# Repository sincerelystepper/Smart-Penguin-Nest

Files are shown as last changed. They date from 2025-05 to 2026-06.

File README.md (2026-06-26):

# Smart Penguin Nest

<p align="center">

# Embedded Environmental Monitoring Platform for African Penguin Conservation

*An ESP32-based multi-sensor embedded instrumentation platform developed for non-invasive wildlife monitoring, environmental data acquisition, and precision weight measurement.*

<br>







</p>

---

> **Engineering Portfolio Project**
>
> This repository documents the design and development of the embedded electronics subsystem for the **Smart Penguin Nest**, a multidisciplinary engineering project created to support environmental monitoring and conservation research of African Penguins through autonomous sensing, embedded instrumentation, and wireless data acquisition.

---

# Table of Contents

* [Project Overview](#project-overview)
* [Research Background](#research-background)
* [Engineering Objectives](#engineering-objectives)
* [System Architecture](#system-architecture)
* [Embedded Electronics Development](#embedded-electronics-development)
* [Hardware Platform](#hardware-platform)
* [Sensor Integration](#sensor-integration)
* [Firmware Architecture](#firmware-architecture)
* [Electronics Design](#electronics-design)
* [Load Cell Calibration](#load-cell-calibration)
* [Communication Architecture](#communication-architecture)
* [Validation & Testing](#validation--testing)
* [Engineering Challenges](#engineering-challenges)
* [Project Gallery](#project-gallery)
* [My Contributions](#my-contributions)
* [Future Improvements](#future-improvements)

---

# Project Overview

The **Smart Penguin Nest** is a prototype embedded environmental monitoring platform developed to assist wildlife researchers in continuously monitoring the environmental conditions experienced by African Penguins during breeding and molting.

The project combines precision instrumentation, environmental sensing, embedded firmware, and wireless communication into a single autonomous monitoring platform capable of acquiring, processing, and transmitting data from multiple sensors.

Although initially developed as a laboratory prototype, the hardware architecture and firmware were designed with future field deployment in mind. Following successful subsystem validation using modular development hardware, a complete electronic schematic was produced in **KiCad** to support future custom PCB revisions and deployment-ready hardware.

This repository focuses specifically on the **embedded electronics engineering**, including firmware development, sensor integration, hardware validation, calibration, and electronic design.

---

# Research Background

African Penguins (*Spheniscus demersus*) have experienced a significant decline in population over recent decades, making continuous ecological monitoring increasingly important for conservation research.

Understanding how environmental conditions influence breeding success, nesting behaviour, and molting requires reliable long-term data acquisition systems capable of operating with minimal disturbance to the animals.

The Smart Penguin Nest project was conceived as a multidisciplinary solution that combines mechanical design, software, and embedded electronics to automate the collection of environmental and physiological measurements from penguin nesting environments.

The embedded subsystem developed within this project provides the sensing and instrumentation layer responsible for acquiring reliable field measurements that can later be analysed by researchers.

---

# Engineering Objectives

The embedded monitoring platform was designed around the following engineering objectives:

* Design a modular embedded instrumentation platform.
* Integrate multiple environmental and physiological sensors.
* Perform accurate body weight measurement using precision load-cell instrumentation.
* Acquire temperature and humidity measurements within the nesting enclosure.
* Enable RFID-based identification capabilities.
* Support infrared temperature sensing.
* Implement wireless communication for remote data transmission.
* Produce a scalable electronics architecture suitable for future PCB implementation.
* Validate subsystem performance through laboratory testing and calibration.

---

# Why This Project Matters

While the immediate application targets wildlife conservation, the engineering principles demonstrated throughout this project are directly applicable to numerous embedded systems domains, including:

| Application | Relevance |
| --- | --- |
| Industrial IoT | Multi-sensor data acquisition  |
| Precision Agriculture | Environmental monitoring |
| Livestock Monitoring | Animal health instrumentation  |
| Smart Buildings | Environmental sensing |
| Cold Chain Monitoring | Temperature logging |
| Industrial Automation | Embedded sensor integration |
| Remote Telemetry | Wireless monitoring systems |
| Scientific Instrumentation | Precision embedded measurement |

The project demonstrates the complete engineering workflow required to transform individual electronic components into an integrated embedded sensing platform suitable for real-world deployment.

---

# Embedded Electronics Development

The embedded subsystem was developed using an iterative engineering workflow, beginning with individual sensor evaluation before progressing toward complete system integration.

Rather than immediately designing a custom PCB, the hardware was first assembled using modular development boards and prototyping components. This accelerated firmware development, simplified subsystem debugging, and allowed each sensing technology to be independently characterized before full system integration.

Following successful laboratory validation, the complete electronic design was captured in **KiCad**, providing a foundation for future PCB revisions and deployment-ready hardware.

The development process followed the typical lifecycle of an embedded instrumentation project:

```text
Requirements Definition
        │
        ▼
Component Selection
        │
        ▼
Power Subsystem Validation
        │
        ▼
Sensor Bring-up
        │
        ▼
Individual Driver Development
        │
        ▼
Sensor Calibration
        │
        ▼
Integrated Firmware Development
        │
        ▼
Wireless Communication
        │
        ▼
Hardware Validation
        │
        ▼
Electronic Schematic Capture
        │
        ▼
Future PCB Design
```

This incremental development approach significantly reduced integration risk by validating each subsystem independently before combining them into the complete monitoring platform.

---

# Hardware Bring-Up

Initial development focused on constructing a working prototype capable of validating each hardware subsystem independently.

The prototype platform combined:

* ESP32 development board
* Precision load-cell interface
* Environmental sensing modules
* RFID identification hardware
* Infrared temperature sensing
* Regulated power distribution
* Wireless communication

Each subsystem was individually verified before being integrated into the complete embedded platform.

<p align="center">

</p>

<p align="center">
<i>Figure 1 — Prototype embedded monitoring platform assembled during subsystem integration and laboratory validation.</i>
</p>

---

# Power Subsystem Validation

Power integrity is one of the most critical aspects of any embedded system.

Before integrating sensors, the power architecture was characterized using laboratory instrumentation to verify voltage regulation, current consumption, and regulator stability under varying operating conditions.

Validation activities included:

* DC-DC buck converter adjustment
* Output voltage verification
* Current consumption measurements
* Regulator stability testing
* System power-up validation

<p align="center">

</p>

<p align="center">
<i>Figure 2 — Initial subsystem power-up using a laboratory bench power supply prior to sensor integration.</i>
</p>

<p align="center">

</p>

<p align="center">
<i>Figure 3 — Output voltage calibration and verification of the DC-DC buck converter before powering embedded electronics.</i>
</p>

<p align="center">

</p>

<p align="center">
<i>Figure 4 — Current consumption measurements performed during hardware characterization and subsystem validation.</i>
</p>

These validation steps ensured reliable power delivery to the ESP32 and all connected sensors before progressing to firmware integration and long-duration testing.

---

---

# Sensor Integration

A primary objective of the Smart Penguin Nest platform was the reliable acquisition of environmental and physiological measurements from multiple sensing technologies.

Rather than relying on a single sensor, the embedded platform integrates a heterogeneous collection of digital, analog and precision instrumentation devices, each selected to monitor a different aspect of the nesting environment.

Each sensor required dedicated firmware development, hardware integration, interface validation and system-level testing before being incorporated into the complete embedded monitoring platform.

---

# Embedded Sensor Suite

| Sensor | Purpose | Interface  |
| --- | --- | --- |
| **HX711 + Load Cell** | Precision body weight measurement | 24-bit ADC |
| **DS18B20** | Ambient temperature sensing | 1-Wire |
| **SHTC3** | Temperature & Relative Humidity | I²C |
| **MLX90614** | Non-contact infrared temperature measurement | I²C |
| **MFRC522** | RFID identification | SPI |

The modular firmware architecture allows each sensing subsystem to operate independently while contributing measurements to a common acquisition and communication framework.

---

# Precision Weight Measurement

## HX711 Load Cell Instrumentation

One of the primary engineering challenges was the accurate measurement of penguin body mass without disturbing the animal.

This was achieved using a strain-gauge load cell coupled with the **HX711**, a precision 24-bit analog-to-digital converter specifically designed for load-cell instrumentation.

Unlike conventional ADCs integrated into microcontrollers, the HX711 provides extremely high measurement resolution together with a programmable gain amplifier, making it particularly suitable for low-level bridge sensor measurements.

The embedded firmware performs:

* Load-cell initialization
* Zero-offset (tare) measurement
* Continuous sampling
* Digital averaging
* Calibration factor application
* Stable weight computation

Calibration parameters are stored within the ESP32's non-volatile memory, allowing the system to preserve calibration between power cycles without requiring repeated field calibration.

<p align="center">

</p>

<p align="center">
<i>Figure 5 — Load-cell calibration procedure used to determine scale factors and improve measurement accuracy.</i>
</p>

---

# Environmental Monitoring

## Temperature Measurement

Environmental temperature is an important parameter when monitoring nesting conditions.

Initial subsystem validation utilised the **DS18B20** digital temperature sensor because of its simplicity, robustness and single-wire communication interface.

The sensor firmware was developed to provide reliable periodic measurements while maintaining low processor overhead.

Development activities included:

* Sensor initialization
* Device discovery
* Temperature acquisition
* Data validation
* Integration into the monitoring framework

As the project evolved, environmental sensing capabilities were expanded through the integration of the **SHTC3**, enabling simultaneous measurement of temperature and relative humidity.

This upgrade simplified hardware integration while improving the quantity of environmental information available to researchers.

---

# Infrared Temperature Measurement

## MLX90614

To complement conventional contact-based measurements, the monitoring platform incorporates the **MLX90614** infrared temperature sensor.

Unlike traditional sensors that require direct physical contact, the MLX90614 measures emitted infrared radiation, allowing non-contact surface temperature estimation.

Within the Smart Penguin Nest platform this capability enables:

* Non-invasive temperature monitoring
* Additional environmental characterization
* Support for future behavioural studies

Firmware development included:

* I²C communication
* Device initialization
* Continuous temperature acquisition
* Sensor validation

---

# RFID Identification

## MFRC522 RFID Module

The embedded platform also integrates an **MFRC522 RFID reader**, providing the capability to uniquely identify tagged animals during future deployments.

The RFID subsystem communicates with the ESP32 through the SPI interface and was integrated as part of the modular firmware architecture.

Development activities included:

* SPI communication
* Card detection
* UID acquisition
* System integration
* Embedded firmware validation

Although the prototype primarily focused on subsystem validation, the RFID interface establishes a foundation for future automated identification and long-term monitoring applications.

---

# Multi-Sensor Integration

Following independent validation, each sensing subsystem was integrated into a unified embedded firmware architecture.

The ESP32 coordinates sensor acquisition, manages communication interfaces, performs measurement processing and prepares environmental data for transmission to the backend server.

The resulting platform demonstrates a scalable embedded architecture capable of supporting additional sensing technologies with minimal firmware modification.

By separating each hardware driver into modular software components, the monitoring platform remains maintainable, reusable and adaptable to future conservation projects.

---

---

---

# Firmware Architecture

The firmware was designed as a modular embedded software stack responsible for coordinating sensor acquisition, system initialization, measurement processing and wireless communication.

Rather than implementing a single monolithic application, development followed an incremental approach where individual sensing subsystems were independently validated before being integrated into the complete monitoring platform.

This significantly reduced integration complexity while improving system reliability during hardware bring-up.

---

# Firmware Design Philosophy

The firmware architecture was developed around several key engineering principles:

* Modular sensor drivers
* Independent subsystem validation
* Reusable hardware abstraction
* Deterministic sensor acquisition
* Persistent calibration storage
* Scalable communication framework
* Maintainable software organization

This approach allows additional sensing technologies to be incorporated with minimal modification to the existing firmware.

---

# Embedded Software Architecture

```text
                    System Reset
                          │
                          ▼
                Hardware Initialization
                          │
                          ▼
              Peripheral Configuration
                          │
                          ▼
               Sensor Driver Initialization
                          │
                          ▼
               EEPROM Configuration Load
                          │
                          ▼
               Wireless Network Connection
                          │
                          ▼
               Continuous Acquisition Loop
                          │
      ┌───────────────────┼────────────────────┐
      │                   │                    │
      ▼                   ▼                    ▼
Load Cell          Environmental         RFID Reader
Measurement            Sensors          Identification
      │                   │                    │
      └───────────────────┼────────────────────┘
                          │
                          ▼
                 Measurement Processing
                          │
                          ▼
                 HTTP Data Packaging
                          │
                          ▼
               Wireless Data Transmission
                          │
                          ▼
                  Repeat Acquisition
```

---

# System Initialization

Following power-up, the firmware performs a complete initialization sequence to ensure every subsystem is operational before measurements begin.

Initialization includes:

* GPIO configuration
* Serial interface initialization
* I²C bus configuration
* SPI peripheral initialization
* One-Wire bus initialization
* WiFi configuration
* EEPROM access
* Sensor verification

Performing these checks during startup ensures that communication failures are detected before entering the continuous monitoring state.

---

# Sensor Driver Architecture

Each hardware peripheral was integrated through an independent software driver responsible for:

* Device initialization
* Communication management
* Data acquisition
* Error checking
* Measurement conversion

This modular organization separates hardware-specific functionality from the higher-level application logic, improving maintainability and simplifying future hardware upgrades.

---

# Measurement Acquisition

During operation, the firmware continuously samples measurements from the connected sensing devices.

Each acquisition cycle consists of:

1. Reading load-cell measurements through the HX711.
2. Acquiring ambient environmental measurements.
3. Reading infrared temperature data.
4. Polling the RFID subsystem.
5. Processing acquired measurements.
6. Preparing the communication payload.
7. Uploading the dataset to the backend server.

This structured acquisition sequence ensures synchronized environmental measurements while maintaining a predictable execution flow.

---

# Calibration Management

Reliable instrumentation requires repeatable calibration.

To eliminate the need for repeated field calibration, calibration coefficients are stored within non-volatile EEPROM memory.

The firmware provides functionality for:

* Zero-offset storage
* Scale-factor storage
* Calibration retrieval during boot
* Calibration updates
* Persistent parameter management

This allows the monitoring platform to retain calibration parameters even after complete power removal.

---

# Embedded Communication

Wireless communication is handled directly by the ESP32.

Once connected to the local WiFi network, the firmware packages the acquired measurements and transmits them to the remote backend through HTTP requests.

Typical transmitted information includes:

* Environmental temperature
* Relative humidity
* Body temperature
* Weight measurements
* Device identification
* Timestamped sensor data

Separating measurement acquisition from communication improves firmware maintainability and enables future migration to alternative communication protocols without redesigning the sensing subsystem.

---

# Reliability Considerations

Throughout development, emphasis was placed on producing firmware suitable for continuous environmental monitoring.

Several design considerations were incorporated during implementation:

* Stable sensor initialization
* Modular peripheral interfaces
* Persistent calibration storage
* Incremental subsystem validation
* Repeatable measurement acquisition
* Simplified debugging through independent sensor testing

Although developed as a prototype research platform, the firmware architecture establishes a strong foundation for future deployment-oriented revisions.

---

---

# Electronics Design

The Smart Penguin Nest embedded subsystem was initially developed using modular development hardware to accelerate firmware development and subsystem validation. This prototyping approach enabled rapid hardware iteration while minimizing the complexity associated with early PCB fabrication.

Following successful validation of the sensing and communication subsystems, the complete electronic design was captured in **KiCad**, providing a scalable hardware foundation for future revisions.

The schematic was developed with several engineering goals in mind:

* Modular sensor interfaces
* Stable power distribution
* Expandable communication buses
* Simplified hardware debugging
* Future PCB implementation
* Improved maintainability

The resulting electronic architecture separates sensing, communication, processing and power management into clearly defined functional blocks suitable for future deployment-ready hardware.

---

## Power Distribution

Reliable power delivery is fundamental to accurate embedded instrumentation.

The prototype platform incorporates regulated power rails supplying the ESP32, sensing peripherals and supporting electronics while maintaining stable operating voltages throughout the system.

Laboratory characterization included:

* Buck converter adjustment
* Output voltage verification
* Current consumption measurements
* Power-up validation
* Regulator stability testing

These measurements ensured stable operation before integrating precision sensing hardware such as the HX711 load-cell amplifier.

---

## Communication Interfaces

The monitoring platform integrates multiple communication protocols within a single embedded node.

| Interface | Connected Devices |
| --- | --- |
| SPI | MFRC522 RFID Reader |
| I²C | MLX90614, SHTC3 |
| One-Wire  | DS18B20 |
| GPIO | HX711 Load Cell Interface |
| WiFi | Remote Backend Communication |

Using dedicated communication buses simplifies firmware development while allowing each sensing subsystem to operate independently.

---

## Schematic Development

The KiCad project included within this repository documents the complete electronic design produced following prototype validation.

The schematic captures:

* ESP32 controller integration
* Sensor interconnections
* Power distribution
* Connector assignments
* Communication buses
* Supporting passive components

Although the prototype was assembled using development modules, the schematic provides the basis for future custom PCB development and production-ready hardware revisions.

---

# Validation & Testing

The embedded platform underwent extensive laboratory testing throughout development.

Rather than validating only the complete system, each subsystem was independently characterized before integration.

Testing activities included:

* Power subsystem verification
* Sensor initialization
* Load-cell calibration
* Temperature sensor validation
* RFID communication testing
* WiFi connectivity
* Backend communication
* Long-duration firmware testing
* System integration

This iterative validation strategy significantly reduced debugging complexity while improving overall system reliability.

---

# Engineering Challenges

Developing a multi-sensor embedded monitoring platform presented several engineering challenges.

## Precision Load-Cell Measurements

Strain-gauge measurements are highly susceptible to electrical noise and mechanical disturbances.

Reliable measurements required careful calibration, averaging and validation of the complete measurement chain.

---

## Stable Power Distribution

Accurate environmental sensing depends upon stable supply voltages.

Power characterization was therefore performed before integrating sensing hardware to eliminate power-related measurement errors.

---

## Multi-Protocol Communication

The ESP32 simultaneously interfaces with devices using SPI, I²C, One-Wire and GPIO interfaces.

Managing multiple communication protocols while maintaining reliable acquisition required careful firmware organization and modular driver development.

---

## Incremental Integration

Rather than attempting complete system integration immediately, each hardware subsystem was independently validated before incorporation into the final monitoring platform.

This significantly simplified debugging while reducing project risk.

---

# Repository Structure

```text
Smart-Penguin-Nest/
│
├── firmware/
│   ├── Sensor Initialization
│   ├── Load Cell Calibration
│   ├── Environmental Monitoring
│   ├── Integrated Firmware
│   └── Supporting Source Code
│
├── schematics/
│   └── KiCad Design Files
│
├── images/
│   ├── Prototype Hardware
│   ├── Laboratory Validation
│   ├── Calibration
│   ├── Power Testing
│   └── System Integration
│
├── docs/
│   └── Project Documentation
│
└── README.md
```

---

# Skills Demonstrated

This project demonstrates practical experience across several embedded systems engineering disciplines.

### Embedded Systems

* ESP32 Firmware Development
* Embedded C++
* Hardware Bring-Up
* Peripheral Integration
* Real-Time Sensor Acquisition

### Electronics

* KiCad Schematic Capture
* Power Distribution
* Embedded Hardware Integration
* Electronic Prototyping
* Hardware Validation

### Instrumentation

* Precision Load-Cell Measurement
* HX711 Integration
* Sensor Calibration
* Environmental Monitoring
* Measurement Processing

### Communication

* WiFi Networking
* HTTP Communication
* REST API Integration
* SPI
* I²C
* One-Wire

### Engineering

* Hardware Debugging
* Laboratory Validation
* Prototype Development
* System Integration
* Technical Documentation

---

# Future Improvements

Although the prototype successfully demonstrated the feasibility of the monitoring platform, several opportunities remain for future development.

Planned improvements include:

* Custom production PCB
* Rugged environmental enclosure
* Battery-powered operation
* Low-power firmware optimization
* OTA firmware updates
* Secure cloud communication
* Remote device diagnostics
* Edge-based data processing
* Improved environmental protection for field deployment

These enhancements would further improve long-term reliability while reducing maintenance requirements during remote operation.

---

# Acknowledgements

This project was completed as part of a multidisciplinary engineering effort supporting wildlife conservation research focused on African Penguins.

While the overall project involved contributions from multiple engineering disciplines, this repository documents my contribution to the embedded electronics subsystem, including firmware development, sensor integration, instrumentation, electronic design and hardware validation.

---

# Closing Remarks

The Smart Penguin Nest demonstrates the complete engineering lifecycle of an embedded environmental monitoring platform—from initial hardware prototyping and sensor evaluation through firmware development, calibration, schematic design and system validation.

Although originally developed to support wildlife conservation research, the underlying architecture is broadly applicable to numerous embedded sensing applications including Industrial IoT, precision agriculture, livestock monitoring, environmental instrumentation and remote telemetry.

This project reflects my approach to embedded systems engineering: build incrementally, validate thoroughly, document carefully and design with future scalability in mind.

---

<p align="center">

**Designed and developed with a passion for Embedded Systems Engineering, Instrumentation and Intelligent Monitoring Platforms.**

</p>

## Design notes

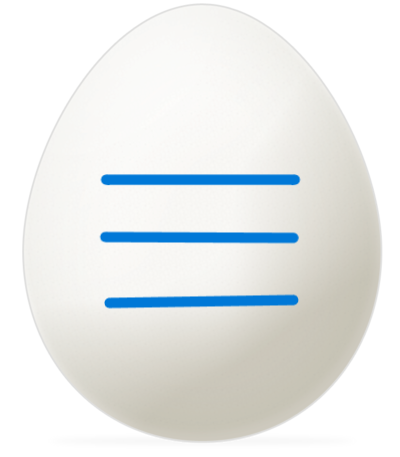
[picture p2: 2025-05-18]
Backend and Front end Application/PenguinApp/src/assets/EGG1.png

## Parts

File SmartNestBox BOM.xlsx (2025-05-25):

Item | Description | Store | Link | quantity | Unit price | Price | Comments
RFID Reader | RFID 13.56MHz Board + tag | Micro Robotics | https://www.robotics.org.za/RC522-MOD-1356 | 1 | R 41.40 | R 41.40
Load Cell Sensor | 5kg Parallel Beam Load Cell Sensor | DIY Electronics | https://www.diyelectronics.co.za/store/load-cells/628-load-cell-sensor-5kg-parallel-beam.html | 4 | R 44.00 | R 176.00
Load Cell interface | HX711 Load Cell Sensor Interface Module | DIY Electronics | https://www.diyelectronics.co.za/store/load-cells/626-hx711-load-cell-sensor-interface-module.html | 1 | R 23.00 | R 23.00 | Just chose cheap available one
Load cell combinator | Load Cells Combinator | Micro Robotics | https://www.robotics.org.za/BOB-13878 | 1 | R 56.35 | R 56.35
Temperature sensor | Humidity & Temperature sensor for stress analysis | DIY Electronics | https://www.diyelectronics.co.za/store/humidity/4210-shtc3-temperature-humidity-sensor-module.html | 1 | R 81.60 | R 81.60
IR Temperature sensor | Non-Contact Temperature Sensor utilises IR light to accurately and rapidly measure temperatures without requiring any direct contact | DIY Electronics | https://www.diyelectronics.co.za/store/temperature/2066-i2c-non-contact-temperature-sensor.html | 1 | R 304.00 | R 304.00
ESp32 Cam | Camera module with EP32 Dev board | DIY Electronics | https://www.diyelectronics.co.za/store/iot/2317-esp32-cam-wifi-bluetooth-camera-development-board.html | 1 | R 182.00 | R 182.00
ESP 32 | ESP32 Dev Board with Wifi-Bluetooth | DIY Electronics | https://www.diyelectronics.co.za/store/iot/4445-nodemcu-32s-esp32-wifi-ble-development-board.html | 1 | R 243.00 | R 243.00 | Changed store to DIY, cheaper
Power Regulator | To convert the 12 V power supply to 5 V for the ESP32 to handle | DIY Electronics | https://www.diyelectronics.co.za/store/switch-mode-modules/1446-lm2596-dc-4540v-to-1537v-adjustable-step-down-buck-module-with-display.html | 1 | R 43.00 | R 43.00 | Cheap one from DIY electronics chosen
 |  |  |  |  |  | R 1150.35
 |  |  |  |  | Budget | R 1500.00
 |  |  |  |  | Remaining | R 349.65
Ordered
Ready to order
Problem
Removed
NFC RFID | RFID Reader Utilised in mass collection for penguin identification | Micro Robotics | https://www.robotics.org.za/RC522-MOD-1356B | 1 | R 141.45 | R 141.45

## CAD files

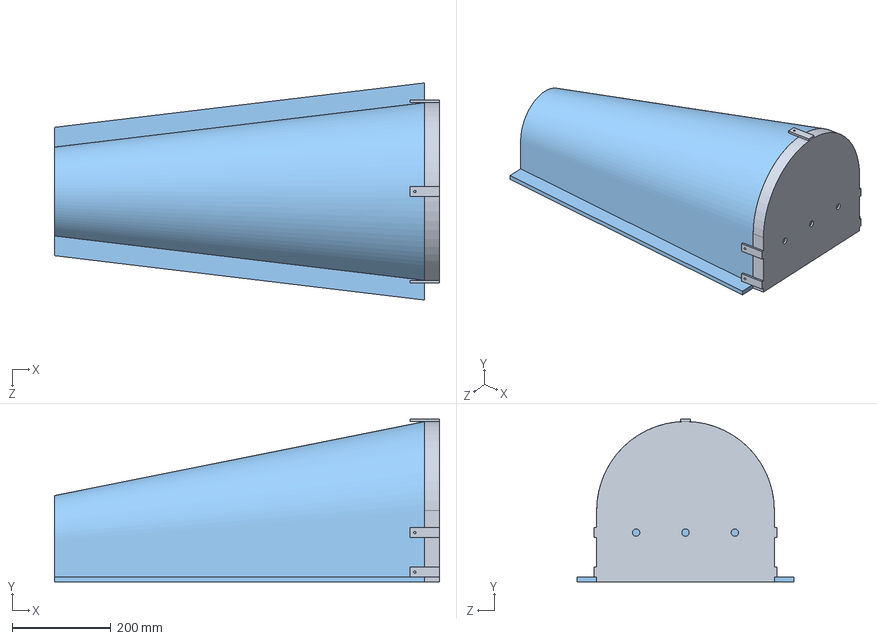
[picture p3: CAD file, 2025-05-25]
Mechanical and Structural Design/SmartNestBox_Assembly.SLDASM
780.0 x 330.0 x 440.0 mm
MainHousing_SmartNest_v4
SensorHousing_SmartNest_v1
BackCover_SmartNest_v1

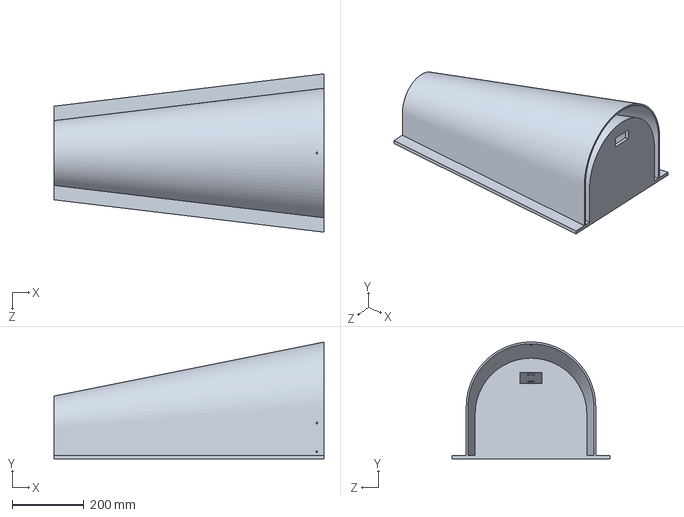
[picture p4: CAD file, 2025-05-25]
Mechanical and Structural Design/MainHousing_SmartNest_v4.SLDPRT
750.0 x 325.0 x 440.0 mm

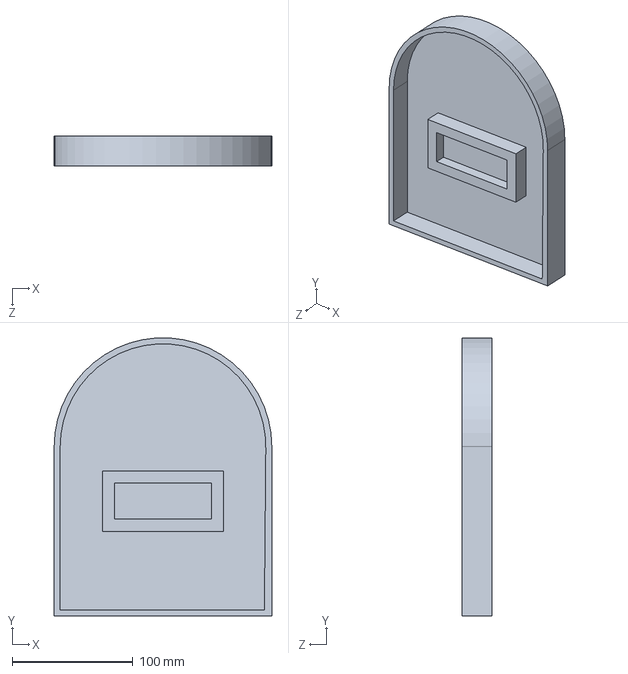
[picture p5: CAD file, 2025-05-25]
Mechanical and Structural Design/Cover_SmartNest_v1.SLDPRT
180.0 x 229.8 x 25.0 mm

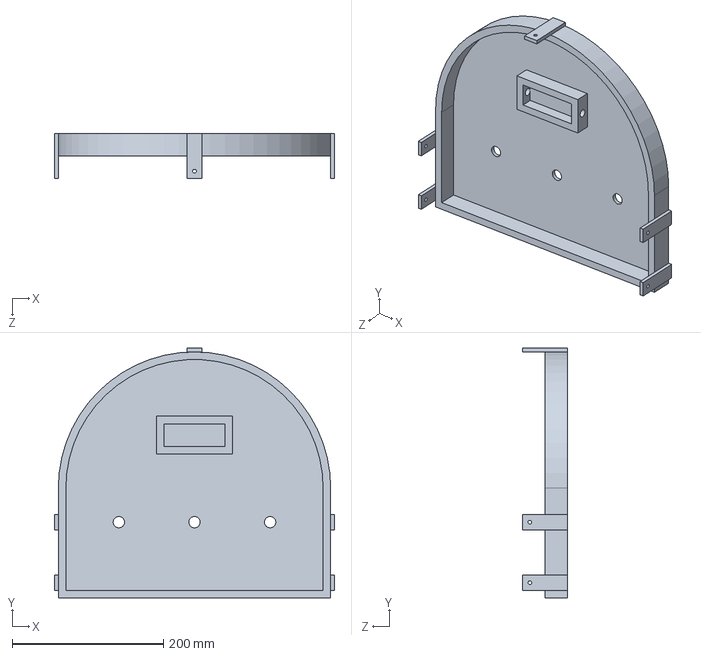
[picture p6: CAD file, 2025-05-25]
Mechanical and Structural Design/BackCover_SmartNest_v1.SLDPRT
370.0 x 330.0 x 60.0 mm

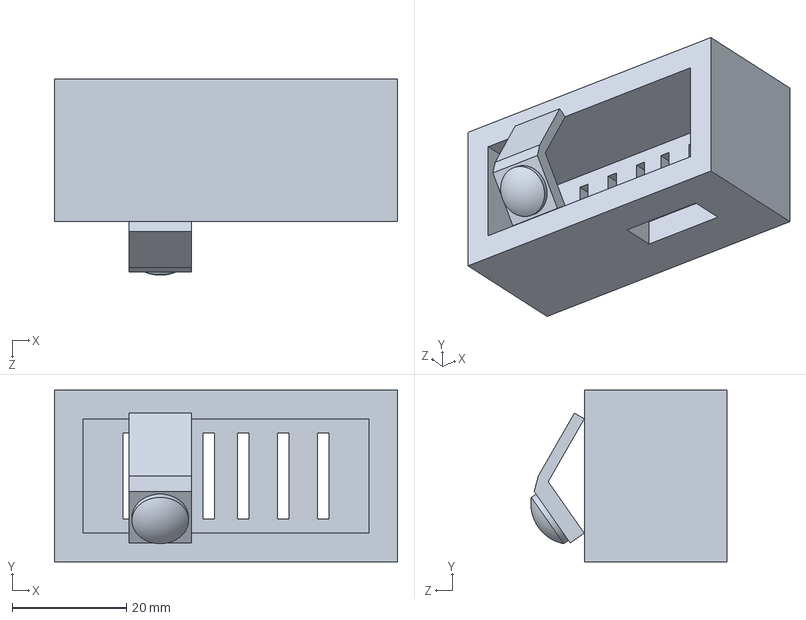
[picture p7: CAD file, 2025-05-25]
Mechanical and Structural Design/SensorHousing_SmartNest_v1.SLDPRT
60.0 x 30.0 x 34.4 mm

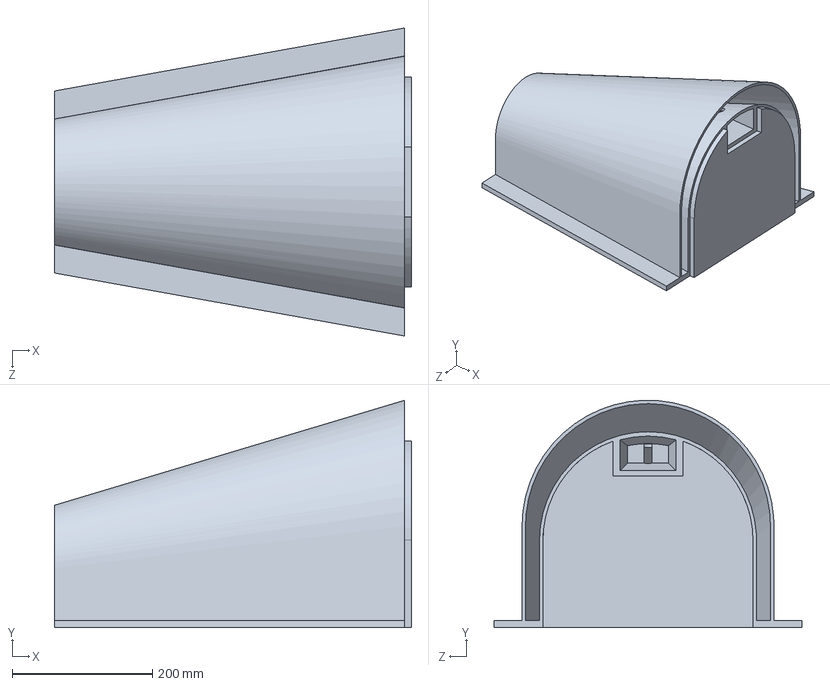
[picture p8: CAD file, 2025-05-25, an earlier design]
Mechanical and Structural Design/MainHousing_SmartNest_v3.SLDPRT
510.0 x 324.9 x 440.0 mm

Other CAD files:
Mechanical and Structural Design/BackCover_SmartNest_v1.SLDDRW
Mechanical and Structural Design/MainHousing_SmartNest_v4.SLDDRW
Mechanical and Structural Design/SensorHousing_SmartNest_v1.SLDDRW

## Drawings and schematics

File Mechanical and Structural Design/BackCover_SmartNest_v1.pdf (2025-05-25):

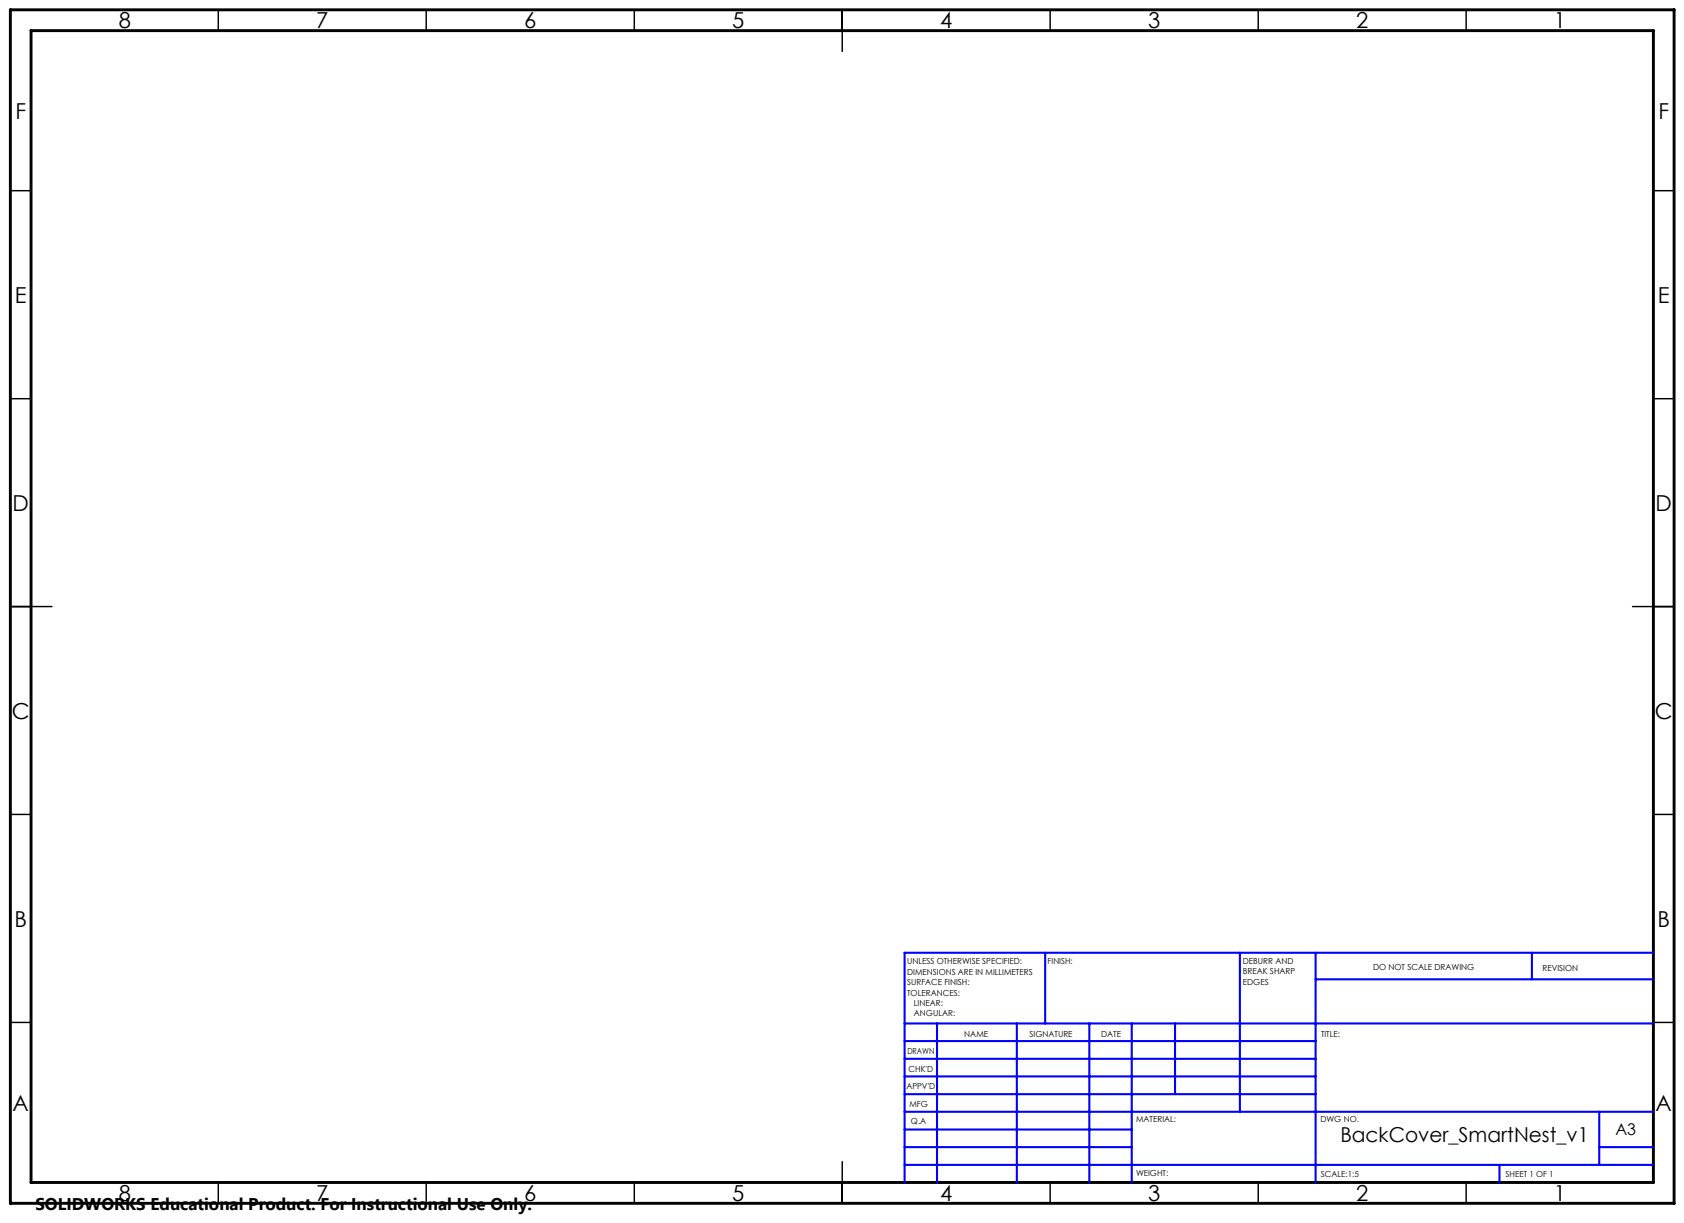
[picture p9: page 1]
FINISH:; DEBURR AND; BREAK SHARP; DO NOT SCALE DRAWING; REVISION; SCALE:1:5; SHEET 1 OF 1

UNLESS OTHERWISE SPECIFIED:
DIMENSIONS ARE IN MILLIMETERS
SURFACE FINISH:
TOLERANCES:
LINEAR:
ANGULAR:

NAME | SIGNATURE | DATE | | | | TITLE:

DRAWN
CHK'D
APPV'D
MFG
Q.A | | | | MATERIAL: | DWG NO. BackCover_SmartNest_v1 | A3

SOLIDWORKS Educational Product. For Instructional Use Only.

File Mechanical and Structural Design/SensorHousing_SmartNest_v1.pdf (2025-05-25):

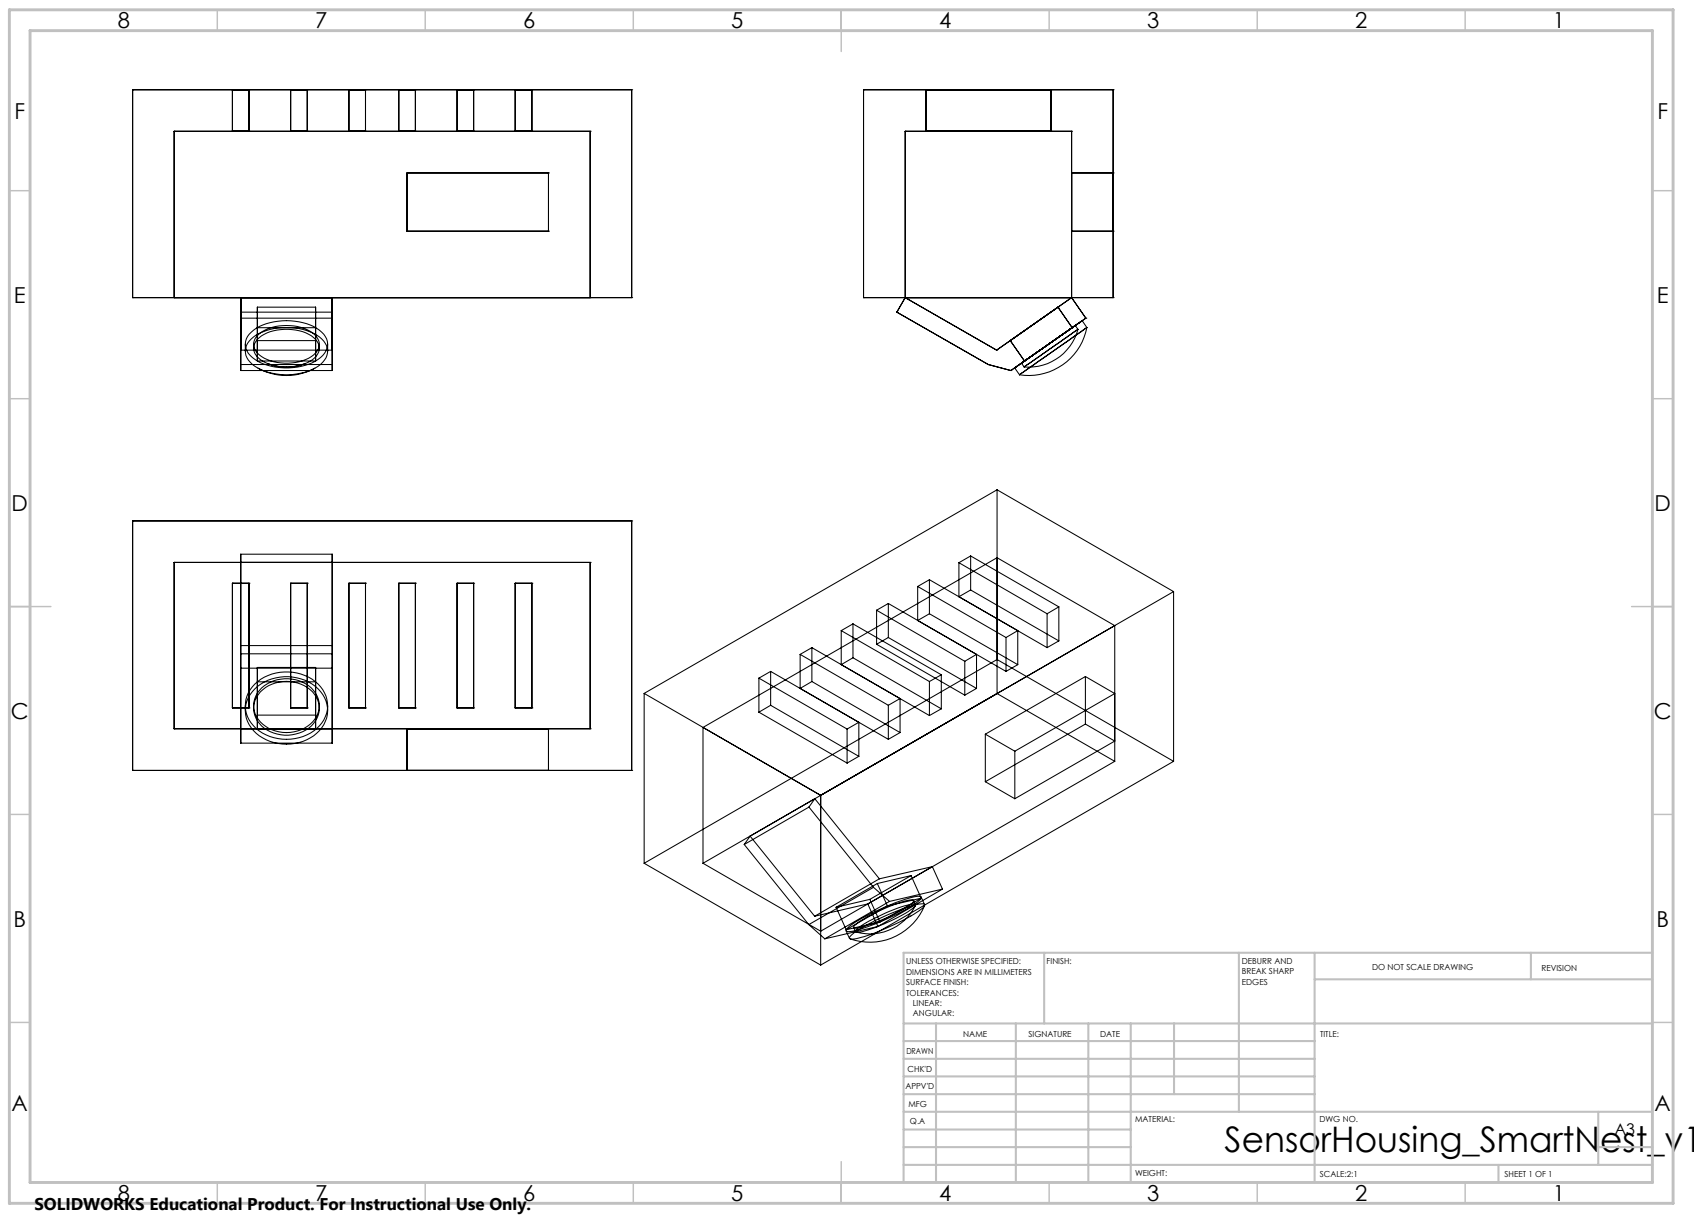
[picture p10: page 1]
FINISH:; DEBURR AND; BREAK SHARP; DO NOT SCALE DRAWING; REVISION; SCALE:2:1; SHEET 1 OF 1

UNLESS OTHERWISE SPECIFIED:
DIMENSIONS ARE IN MILLIMETERS
SURFACE FINISH:
TOLERANCES:
LINEAR:
ANGULAR:

NAME | SIGNATURE | DATE | | | | TITLE:

DRAWN
CHK'D
APPV'D
MFG
Q.A | | | | MATERIAL: | DWG NO. | A3

SOLIDWORKS Educational Product. For Instructional Use Only.

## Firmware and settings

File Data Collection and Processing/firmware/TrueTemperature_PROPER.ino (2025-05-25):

#include <WiFi.h>
#include <HTTPClient.h>
#include <ArduinoJson.h>
#include <Wire.h>
#include "Adafruit_SHTC3.h"
#include <Adafruit_MLX90614.h>

// Wi-Fi credentials
const char* ssid = "Kendal 1 Wi-Fi";
const char* password = "Kendalone!";

// API endpoint
const char* serverName = "https://server-api-609n.onrender.com/data";

Adafruit_SHTC3 shtc3 = Adafruit_SHTC3();
Adafruit_MLX90614 mlx = Adafruit_MLX90614();

float ambient_temp_shtc3 = 0.0;
float ambient_temp_ir = 0.0;
float object_temp_ir = 0.0;
float corrected_chick_temp = 0.0;

// Temperature thresholds
#define WARNING_TEMP 25.0
#define CRITICAL_TEMP 27.0

#define LED_PIN 2  // Onboard LED pin

bool plotterMode = true;  // Toggle between Serial Plotter and Monitor modes

void setup() {
  Serial.begin(115200);
  delay(500);

  Wire.begin();

  if (!shtc3.begin()) {
    Serial.println("ERROR: Couldn't find SHTC3 sensor!");
    while (1) delay(10);
  }

  if (!mlx.begin()) {
    Serial.println("ERROR: Could not initialize MLX90614 sensor!");
    while (1) delay(10);
  }

  WiFi.mode(WIFI_STA);
  WiFi.begin(ssid, password);
  
  if (!plotterMode) {
    Serial.println("SYSTEM: Initializing penguin monitoring system...");
    Serial.print("NETWORK: Connecting to ");
    Serial.print(ssid);
  }

  int retries = 0;
  while (WiFi.status() != WL_CONNECTED && retries < 40) {
    delay(250);
    if (!plotterMode) Serial.print(".");
    retries++;
  }

  if (!plotterMode) {
    if (WiFi.status() == WL_CONNECTED) {
      Serial.println("\nNETWORK: Connected successfully!");
      Serial.print("NETWORK: IP Address: ");
      Serial.println(WiFi.localIP());
    } else {
      Serial.println("\nERROR: Failed to connect to Wi-Fi");
    }
    Serial.println("SYSTEM: Ready for temperature monitoring\n");
  }

  pinMode(LED_PIN, OUTPUT);
  digitalWrite(LED_PIN, LOW);
}

void blinkLED(int interval) {
  for (int i = 0; i < 3; i++) {
    digitalWrite(LED_PIN, HIGH);
    delay(interval);
    digitalWrite(LED_PIN, LOW);
    delay(interval);
  }
}

void loop() {
  // Sensor readings
  sensors_event_t humidity, temp;
  shtc3.getEvent(&humidity, &temp);
  ambient_temp_shtc3 = temp.temperature;
  object_temp_ir = mlx.readObjectTempC();
  ambient_temp_ir = mlx.readAmbientTempC();
  corrected_chick_temp = object_temp_ir + (ambient_temp_shtc3 - ambient_temp_ir);

  // Enhanced Serial Outputs
  if (plotterMode) {
    // Serial Plotter format with labels
    Serial.print("ChickTemp:");
    Serial.print(corrected_chick_temp);
    Serial.print(",AmbientTemp:");
    Serial.print(ambient_temp_shtc3);
    Serial.print(",IRTemp:");
    Serial.println(object_temp_ir);
  } else {
    // Detailed Serial Monitor output
    Serial.println("\n=== SENSOR READINGS ===");
    Serial.print("SHTC3 Ambient Temp: ");
    Serial.print(ambient_temp_shtc3);
    Serial.println(" °C");
    
    Serial.print("MLX90614 Ambient Temp: ");
    Serial.print(ambient_temp_ir);
    Serial.println(" °C");
    
    Serial.print("MLX90614 Object Temp: ");
    Serial.print(object_temp_ir);
    Serial.println(" °C");
    
    Serial.print("Corrected Chick Temp: ");
    Serial.print(corrected_chick_temp);
    Serial.println(" °C");
    Serial.println("======================");
  }

  // Temperature alerts
  if (corrected_chick_temp >= CRITICAL_TEMP) {
    if (!plotterMode) Serial.println("ALERT: CRITICAL TEMPERATURE DETECTED!");
    blinkLED(100);
  } else if (corrected_chick_temp >= WARNING_TEMP) {
    if (!plotterMode) Serial.println("WARNING: Elevated temperature detected");
    blinkLED(500);
  } else {
    digitalWrite(LED_PIN, LOW);
    delay(1000);
  }

  // Data transmission
  if (WiFi.status() == WL_CONNECTED) {
    HTTPClient http;
    http.begin(serverName);
    http.addHeader("Content-Type", "application/json");

    StaticJsonDocument<200> doc;
    doc["corrected_chick_temp"] = corrected_chick_temp;
    doc["timestamp"] = millis();

    String requestBody;
    serializeJson(doc, requestBody);

    int httpResponseCode = http.POST(requestBody);
    if (!plotterMode) {
      if (httpResponseCode > 0) {
        Serial.print("DATA: Upload successful (HTTP ");
        Serial.print(httpResponseCode);
        Serial.println(")");
      } else {
        Serial.print("ERROR: Upload failed (HTTP ");
        Serial.print(httpResponseCode);
        Serial.println(")");
      }
    }
    http.end();
  } else if (!plotterMode) {
    Serial.println("NETWORK: Wi-Fi disconnected - data not uploaded");
  }

  delay(1000);  // 1-second delay between readings
}

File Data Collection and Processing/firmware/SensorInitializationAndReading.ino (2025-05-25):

#include <Wire.h>
#include <SPI.h>
#include <HX711.h>
#include <MFRC522.h>
#include <OneWire.h>
#include <DallasTemperature.h>
#include <Adafruit_MLX90640.h>

// HX711 Load Cell setup
#define DOUT  21
#define CLK   22
HX711 scale;

// RFID RC522 setup
#define RST_PIN 22
#define SS_PIN  21
MFRC522 rfid(SS_PIN, RST_PIN);

// DS18B20 Temperature Sensor setup
// got the code for DS11 tho. 
#define ONE_WIRE_BUS 16
OneWire oneWire(ONE_WIRE_BUS);
DallasTemperature sensors(&oneWire);

// MLX90640 Thermal Camera setup
Adafruit_MLX90640 mlx;

void setup() {
  // Start serial communication
  Serial.begin(115200);
  
  // Initialize Load Cell (HX711)
  scale.begin(DOUT, CLK);
  Serial.println("HX711 Load Cell Initialized!");
  
  // Initialize RFID RC522
  SPI.begin();
  rfid.PCD_Init();
  Serial.println("RFID Reader Initialized!");
  
  // Initialize DS18B20 Temperature Sensor
  sensors.begin();
  Serial.println("DS18B20 Temperature Sensor Initialized!");
  
  // Initialize MLX90640 Thermal Camera
  Wire.begin();
  if (!mlx.begin()) {
    Serial.println("MLX90640 not detected");
    while (1);
  }
  Serial.println("MLX90640 Thermal Camera Initialized!");
}

void loop() {
  // Reading weight from HX711
  if (scale.is_ready()) {
    long weight = scale.get_units(10);  // Average reading from 10 samples
    Serial.print("Weight: ");
    Serial.println(weight);
  } else {
    Serial.println("HX711 not connected.");
  }

  // Reading RFID data
  if (rfid.PICC_IsNewCardPresent()) {
    if (rfid.PICC_ReadCardSerial()) {
      Serial.print("RFID Tag ID: ");
      for (byte i = 0; i < rfid.uid.size; i++) {
        Serial.print(rfid.uid.uidByte[i], HEX);
      }
      Serial.println();
    }
  }

  // Reading Temperature from DS18B20, or maybe DTI11
  sensors.requestTemperatures();  // Request temperature reading
  float temperature = sensors.getTempCByIndex(0);  // Get temperature in Celsius
  Serial.print("Temperature: ");
  Serial.println(temperature);

  // Reading Thermal data from MLX90640
  float frame[32 * 24];  // Array to store thermal data
  mlx.getFrame(frame);  // Get thermal data
  Serial.print("Thermal data (first 10 values): ");
  for (int i = 0; i < 10; i++) {
    Serial.print(frame[i], 2);
    Serial.print(", ");
  }
  Serial.println();

  // Delay for readability
  delay(2000); // maybe 1 sec 
}


// how to add the camera in

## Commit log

2025-04-13 Chnaged API entries to temperature and timestamp
2025-05-17 Updated download button
2025-05-17 Updated button to split button
2025-05-17 Updated button/dropdown styles
2025-05-22 Fixed button drop downs
2025-05-25 Reorganized folders + added Mech design folder
    [BackCover_SmartNest_v1.SLDDRW, BackCover_SmartNest_v1.SLDPRT, Cover_SmartNest_v1.SLDPRT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]
2025-05-25 Added collect and process folder
    [Kicad Schematic.kicad_pcb, Kicad Schematic.kicad_sch, dataCollectionProcessing.kicad_pcb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]
2026-06-26 Enhance README with sensor integration details
    Added sections on sensor integration, embedded sensor suite, and multi-sensor integration to the README.
2026-06-26 Enhance README with firmware architecture details
    Expanded the README to include detailed sections on firmware architecture, design philosophy, initialization, sensor driver architecture, measurement acquisition, calibration management, communicatio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
2026-06-26 Expand README with comprehensive project details
    Added detailed sections on electronics design, power distribution, communication interfaces, schematic development, validation and testing, engineering challenges, repository structure, skills demons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
